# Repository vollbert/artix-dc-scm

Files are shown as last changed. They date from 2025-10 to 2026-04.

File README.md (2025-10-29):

# Artix DC-SCM

Copyright (c) 2020-2025 [Antmicro](https://www.antmicro.com)





## Overview

This repository contains design files for an open-source Baseboard Management Controller (BMC) module based on the Xilinx Artix-7 FPGA family, designed in accordance with the Data Center Secure Control Module (DC-SCM) specification of Open Compute Project (OCP).

The design files were prepared in KiCad 9.x.

## Repository structure

The main repository directory contains KiCad PCB project files, a LICENSE and README.
The remaining files are stored in the following directories:

* `img` - contains graphics for this README

## Key Features

* Artix-7 FPGA - XC7A100T-FGG484
* DC-SCI standard 168-pin 4C+ edge connector
* On-board DDR3 DRAM (AS4C256M16D3) and eMMC (MTFC16GAPALNA-AIT)
* 4x SPI FLASH memory
* Gigabit Ethernet over KSZ9031RNXCA PHY
* JTAG connector
* Host and client USB (over USB3300-EZK-TR PHY)
* M.2 NVMe interface
* 13x I2C buses, 4x I3C buses
* 2x UART 
* SPI connector
* RoT module connector
* TPM SPI connector

## Block diagram



License
=======

This project is published under the [Apache-2.0](LICENSE) license.

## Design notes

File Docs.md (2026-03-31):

## To Do

- Route the DDR3 memory
- Do the Delay Matching for DDR3 memory
- check the validation of the pinout
- get the Correct values for the 100 Ohm differential pairs
- place the capacitors and resistors to the correct locations for the ddr3 chip
    - 4 capacitors were missing in original

- for next iteration
    - what to do with rot module interface
        - only keep one flash

SYS_PWROK_R - HPM_STBY_RST_N_R
SGPIO0_D0 U2 - SYS_PWRBTN_N_R V5
SGPIO0_DI W4 - SYS_PWROK_R p16
CHASI#_R Y3 - DBP_PREQ_N_R V2
SGPIO0_CLK W5 - DBP_PRDY_N_R W2
I2C[10]_SDA W6 - RST_PLTRST_BUF_N_R W1
SGPIO1_D0 Y6 - Spare1_R AA1
Spare0r y6 - spare1_r
SGPIO0_LD V7 - rot_cpu_rst_N_r
RSVD2 y7 - Chasi#_r
spare0_r y2 - i2c[11]_scl
irq_N_r ab1 - sgpio1_di
espi_io0 K17 - i2c[8]_sda
i2c[7]_sda E13 - espi_io1
i2c[7]_scl E13 - espi_io3 L16
i2c[6]_sda G13 - espi_reset_n
spi0_cs_n_r - espi_alert_n h18
spi0_clk_r - espi_cs0_n K18
uart0_scm_rx - espi_clk L18
espi_cs1_n - i2c[6]_clk

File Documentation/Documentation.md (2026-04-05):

## To Do

# DDR3
- [ ] Find Assembly house in munich
- [x] Route the DDR3 memory
- [ ] impedance matching
	- 50 ohm single ended
		layer 3 and 5 trace thickness 0.175mm from multicb datasheet 
	- 100 Ohm differential 
		- 0.11 / 0.16mm (used calculator tool) 
- [ ] include all tha package delays
- [ ] replace obsolete .. with alternative
- MT41K256M16TW-093:P:  DDR3L 256x16 with speed grade 2133
	- make s skew limits much more relaxed

- [ ] Do the Delay Matching for DDR3 memory
![[Pasted image 20260326165011.png]]
![[Pasted image 20260403101223.png]]
Currently current configuration max dq skew 67ps for pair 1
- [x] check the validation of the pinout
	![[Pasted image 20260325133729.png]]
	![[Pasted image 20260325133813.png]]
- [ ] get the Correct values for the 100 Ohm differential pairs
- [ ] place the capacitors and resistors to the correct locations for the ddr3 chip
    - 4 capacitors were missing in original
	- Capacitors way to far from the power pins
	- Why are a handful of caps footprint 0201 x5R +-20 percent (makes no sense) either all or none for the same class. makes manufacturing harder
- [x] Changed Clock Termination According to UG589 from 
		![[Pasted image 20260325125533.png]]
		to
		![[Pasted image 20260325125712.png]]
		![[Pasted image 20260325125657.png]]
- [ ] 

## Ethernet
- [ ] "RGMII v2.0 is supported at 1.8V in HP I/O or up to 2.5V in HR I/O"  
	- i think i stay with the 3.3V 
	![[Pasted image 20260325150038.png]]	
- [.] Add series termination resistors on transmitter sides for rgmii
- [ ] impedance matching 50 rgmii and 100 ohm differential ethernet 

## USB

## eMMC
- [ ] chip obsolete find alternative to MTFC16GAPALNA-AIT 
	- all micron parts with unclear lifecycle information
	- SFEM016GB2ED1TO-I-5E-111-STD : 16Gb better write speed and active lifecycle

# Things to consider for Second design
- Better stackup with thinner traces (other manufacturer)
- replace 0402 with 0201 resistors and caps to improve routing
- clock with higher than 400mhz ddr but check impedance (i think you need 40 ohm for this)

## Pcie
- Differential Pair 85 Ohm +- 10%

## Qspi
Routing is not optimal.. place flash further to the fpga and maybe only use one flash without ROT Module connector.

## New Caps
- for 4.7uF use 0603: smaller packages have bigger voltage drop at 3.3V
	- Voltage rating doesn't affect the voltage drop therefore use 6.3V rated 
	- [**C0603C475K9PAC**](https://yageogroup.com/products?search=C0603C475K9PAC)  	
	- 

# JTAG Chip not available
- use this instead -> JTAG-HS3 Programming Cable
- https://www.digikey.de/en/products/detail/digilent-inc/410-299/5015666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

# Consolidate BOM
- Reassign all parts in Kicad directly

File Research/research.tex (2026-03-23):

\documentclass[11pt]{article}
\usepackage[utf8]{inputenc}
\usepackage[margin=1in]{geometry}
\usepackage{booktabs}
\usepackage{hyperref}
\usepackage{graphicx}

% \title{Design Review: Artix DC-SCM PCB Fabrication}
% \author{Fabian}
% \date{\today}

\begin{document}

% \maketitle

\section{BOM Obsolescence}
The following components are obsolete:
\begin{itemize}
    \item \textbf{DDR3 SDRAM:} Alliance AS4C256M16D3-12BIN. 
    \item \textbf{eMMC Flash:} Micron MTFC16GAPALNA-AIT-ND.
\end{itemize}

\section{PCB Fabrication \& DFM Blockers}
\begin{itemize}
    \item \textbf{Non-Standard Via Stackup:} Current design uses L1--L6 blind vias. This is asymmetrical for an 8-layer board and requires expensive sequential lamination. Or it can't be manufactured by most manufacturers.

    \item \textbf{Unoptimized DRC Rules:} The Default Design constraints are messy(figure \ref{fig:design-constrains}). For example 0mm clearance between Tracks. After i changed those values to minimum values of different manufacturers there are some DRC Errors. (Example \ref{fig:weirdtrace}) 

    \item Different Stackup in Fabrication Files, Website and in the Kicad setup: I checked the impedances for the different stackups and only the impedance in the fabrication file leads to the correct impedance. 

    \item Unnecessary restrictive constrains makes the design not well suited for Manufacturability which is why most manufacturers are not able to manufacture the board. 

\end{itemize}

\begin{figure}[h]
  \centering
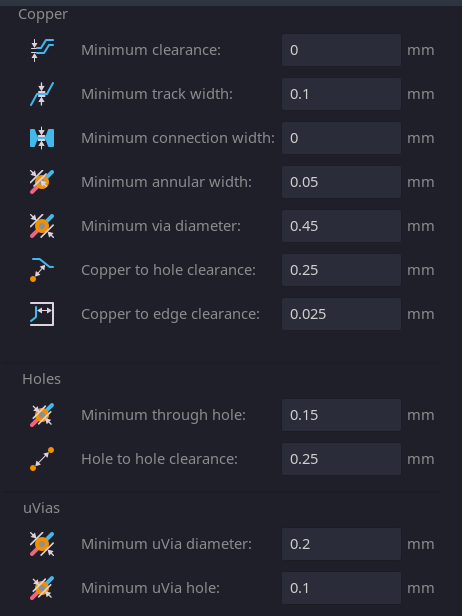
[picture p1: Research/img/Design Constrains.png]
  
  \caption{}
  \label{fig:design-constrains}
\end{figure}

\begin{figure}[h]
  \centering
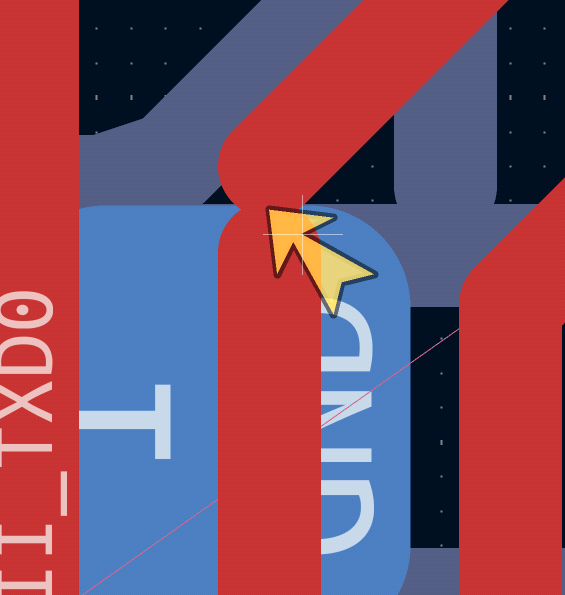
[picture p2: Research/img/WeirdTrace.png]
  
  \caption{}
  \label{fig:weirdtrace}
\end{figure}

\section{Impedance Issues}

Impedances are matched using Online Calculators. Kicads Internal tool leads to different Impedance values. Online Calculators are not sufficient for small traces and spacing!!

\section{Before Ordering}
\begin{itemize}
  \item Check Minor DRC Errors
  \item Try to get rid of 1-6 vias and replace them with through hole vias.
  \item Choose one manufacturer and change the traces to have the right impedance for their stackup
  \item Check Impedances \textbf{Impedance Control}: Factory changes the traces based on their parameters.
\end{itemize}

\section{PCB Manufacturers}
Since there are so hard constrains i had to search for many different manufacturers and see if they are able to manufacture the board. So far i checked the following ones. For the prices i calculated 5 boards since it is the minimum for many assembly houses.
\begin{itemize}
  \item \textbf{PCBWay}: I requested a quote from them to have a baseline for the price. They are able to manufacture any layer HDI boards. For 5 boards: \$758.53(Without tax) + 
\$ 1656.37 for assembly including the parts
  \item \textbf{Eurocircuit}: Can't manufacture 1-6 vias for 8 layer board. Also no via stacking. Without those vias: € 3538.92 (Only so expensive because of hard constrains)
  \item \textbf{Wuerth Electronics}1-6 via not possible for their normal stackups. € 1.320,75	with less strict constrains
  \item \textbf{Multi-CB} Should be capable of creating the PCB but has no assembly service. Since This is a really custom stackup i had to request manually and still have no reply. (706.52 € for only one pcb)
  \item \textbf{Leiton}Should be capable of creating the PCB and assemble but since this is a really special request this is only done manually and i have no reply yet.
\end{itemize}

\section{Modification Estimate: 32x IO Integration}
Should be doable. This (figure \ref{fig:areaasic}) has some space that should be enough to route the traces to the asic depending on the footprint size. If there is not enough space I have to move some footprints and do most of the routing again. Since the FPGA has a relatively large pitch maybe it would be better to do the routing again and optimize for Manufacturability.

Check IO voltages

\begin{figure}[h]
  \centering
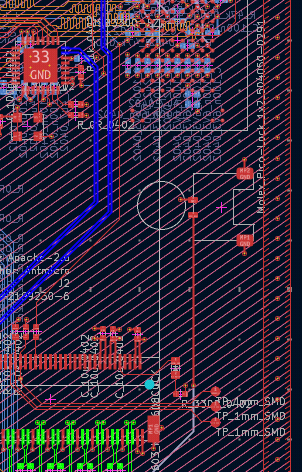
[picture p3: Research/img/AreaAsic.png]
  
  \caption{}
  \label{fig:areaasic}
\end{figure}

\section{Impedance Control Requirements}
\begin{center}
\begin{tabular}{l l l}
\toprule
\textbf{Interface} & \textbf{Signal Type} & \textbf{Target Impedance} \\
\midrule
PCIe Gen 2 & Differential Pairs & 85$\Omega \pm 10\%$ \\
Ethernet (Media) & Differential Pairs & 100$\Omega \pm 10\%$ \\
RGMII (MAC side) & Single-Ended & 50$\Omega \pm 10\%$ \\
USB & Differential & 90$\Omega \pm 15\%$ \\
\bottomrule
\end{tabular}
\end{center}

\section{DDR3}

Generally, single impedances (CA, Control \& DQ’s) are 50Ω (+/- 10\%) 
and differential impedances (Clocks, DQS’s) are nominally 100Ω (+/- 10\%) and are typically routed on inner layers if 
possible.
\\

The following are general guidelines for PDN development in DDR3 board designs. 
\begin{itemize}
\item1. Solid Power and Ground planes should be used in DDR3 routing areas. 
\item2. Place a 0.1uF cap and 0.01uF as close as possible for every VDDQ pin. 
\item3. VTT decoupling should be as close to the components and pull-up resistors as possible. 
\item4. Place a 0.1uF decoupling cap between VTT and VDD. 
\item5. Low ESL decoupling capacitors should be used, and routing should be carefully evaluated to minimize 
inductance. 
\item 6. Power connections from supply planes to vias for device pins or decoupling capacitors should be as short ($<$8 
mils) and as wide as possible (trace widths should be the same or larger than the via size) to minimize trace 
impedance. 
\end{itemize}

\section{changed}

- changed ddr3\_clk\_p with ddr3\_a9 (easier routing)
- changed ddr3\_clk\_n with ddr3\_a5

\end{document}

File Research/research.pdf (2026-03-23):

## 1 BOM Obsolescence

The following components are obsolete:

- DDR3 SDRAM: Alliance AS4C256M16D3-12BIN.
- eMMC Flash: Micron MTFC16GAPALNA-AIT-ND.

## 2 PCB Fabrication & DFM Blockers

- Non-Standard Via Stackup: Current design uses L1–L6 blind vias. This is asymmetrical for an 8-layer board and requires expensive sequential lamination. Or it can’t be manufactured by most manufacturers.
- Unoptimized DRC Rules: The Default Design constraints are messy(figure 1). For example 0mm clearance between Tracks. After i changed those values to minimum values of different manufacturers there are some DRC Errors. (Example 2)
- Different Stackup in Fabrication Files, Website and in the Kicad setup: I checked the impedances for the different stackups and only the impedance in the fabrication file leads to the correct impedance.
- Unnecessary restrictive constrains makes the design not well suited for Manufacturability which is why most manufacturers are not able to manufacture the board.

## 3 Impedance Issues

Impedances are matched using Online Calculators. Kicads Internal tool leads to different Impedance values. Online Calculators are not sufficient for small traces and spacing!!

## 4 Before Ordering

- Check Minor DRC Errors
- Try to get rid of 1-6 vias and replace them with through hole vias.
- Choose one manufacturer and change the traces to have the right impedance for their stackup
- Check Impedances Impedance Control: Factory changes the traces based on their parameters.

## 5 PCB Manufacturers

Since there are so hard constrains i had to search for many different manufacturers and see if they are able to manufacture the board. So far i checked the following ones. For the prices i calculated 5 boards since it is the minimum for many assembly houses.

- PCBWay: I requested a quote from them to have a baseline for the price. They are able to manufacture any layer HDI boards. For 5 boards: $758.53(Without tax) + $ 1656.37 for assembly including the parts

- Eurocircuit: Can’t manufacture 1-6 vias for 8 layer board. Also no via stacking. Without those vias: € 3538.92 (Only so expensive because of hard constrains)
- Wuerth Electronics1-6 via not possible for their normal stackups. € 1.320,75 with less strict constrains
- Multi-CB Should be capable of creating the PCB but has no assembly service. Since This is a really custom stackup i had to request manually and still have no reply. (706.52 € for only one pcb)
- LeitonShould be capable of creating the PCB and assemble but since this is a really special request this is only done manually and i have no reply yet.

## 6 Modification Estimate: 32x IO Integration

Should be doable. This (figure 3) has some space that should be enough to route the traces to the asic depending on the footprint size. If there is not enough space I have to move some footprints and do most of the routing again. Since the FPGA has a relatively large pitch maybe it would be better to do the routing again and optimize for Manufacturability.
Check IO voltages

## 7 Impedance Control Requirements

Interface | Signal Type | Target Impedance
PCIe Gen 2 | Differential Pairs | 85Ω ± 10%
Ethernet (Media) | Differential Pairs | 100Ω ± 10%
RGMII (MAC side) Single-Ended | 50Ω ± 10%
USB | Differential | 90Ω ± 15%

## 8 DDR3

Generally, single impedances (CA, Control & DQ’s) are 50Ω (+/- 10%) and differential impedances (Clocks, DQS’s) are nominally 100Ω (+/- 10%) and are typically routed on inner layers if possible.

The following are general guidelines for PDN development in DDR3 board designs.

- 1. Solid Power and Ground planes should be used in DDR3 routing areas.
- 2. Place a 0.1uF cap and 0.01uF as close as possible for every VDDQ pin.
- 3. VTT decoupling should be as close to the components and pull-up resistors as possible.
- 4. Place a 0.1uF decoupling cap between VTT and VDD.
- 5. Low ESL decoupling capacitors should be used, and routing should be carefully evaluated to minimize inductance.
- 6. Power connections from supply planes to vias for device pins or decoupling capacitors should be as short (<8 mils) and as wide as possible (trace widths should be the same or larger than the via size) to minimize trace impedance.

## 9 changed

- changed ddr3 clk p with ddr3 a9 (easier routing) - changed ddr3 clk n with ddr3 a5


Figure 1:

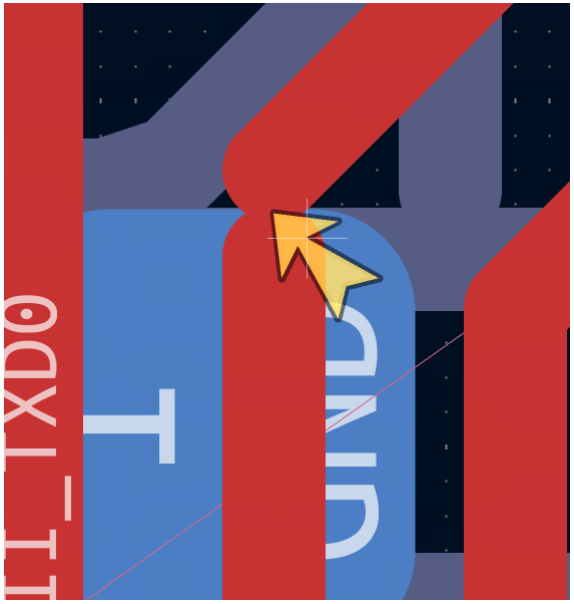
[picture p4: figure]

Figure 2:

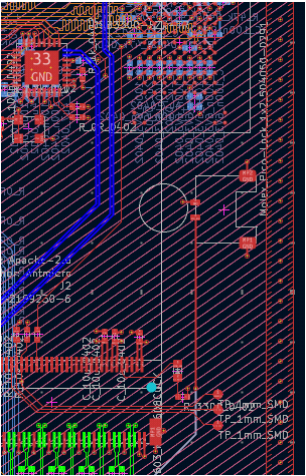
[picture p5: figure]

Figure 3:

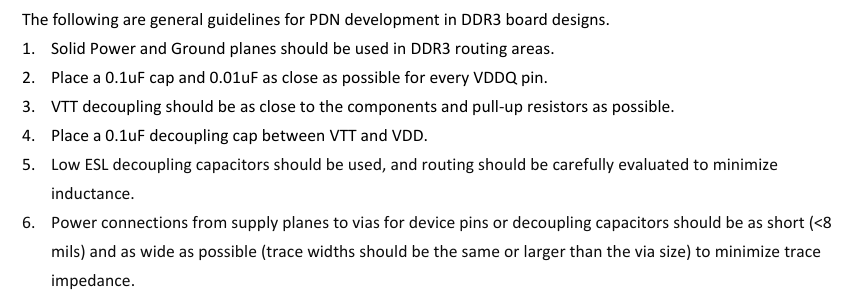
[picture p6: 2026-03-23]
Research/img/DDR3Rules.png

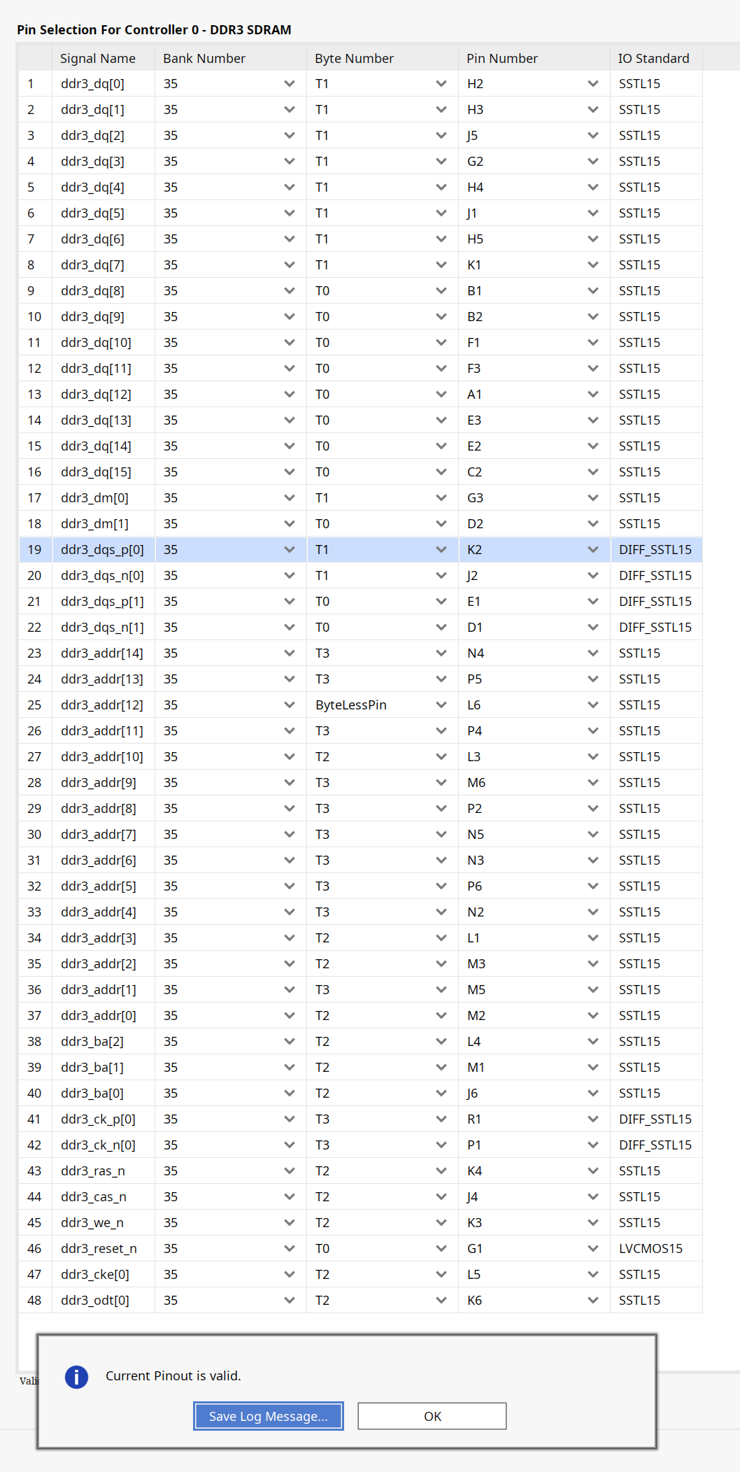
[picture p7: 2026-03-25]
Documentation/Pasted image 20260325133729.png

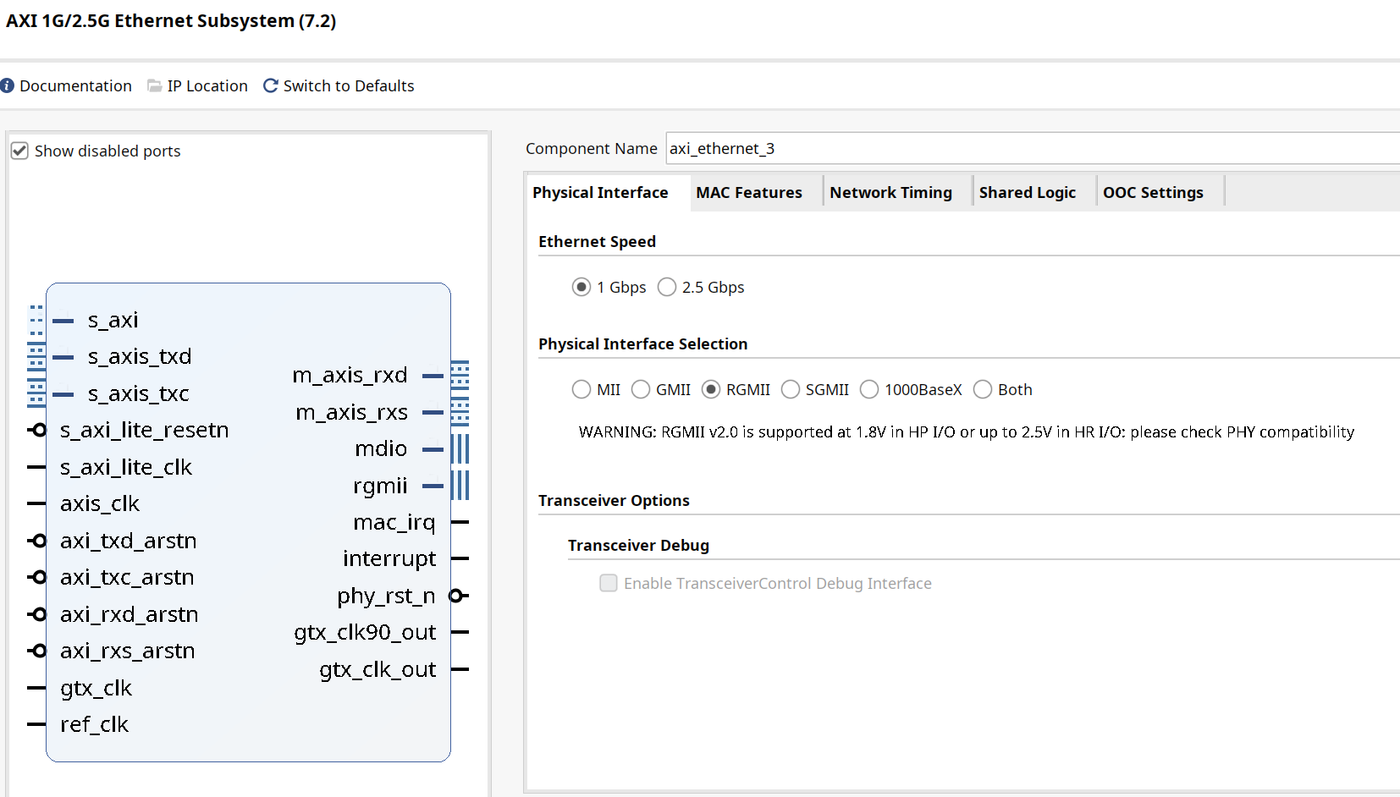
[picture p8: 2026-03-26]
Documentation/Pasted image 20260325150038.png

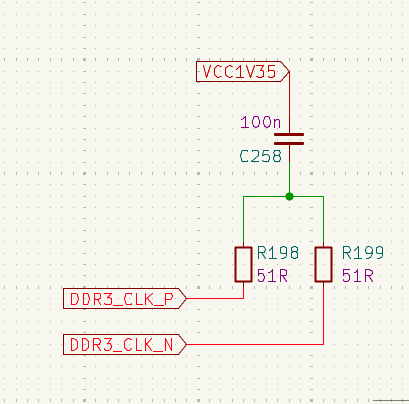
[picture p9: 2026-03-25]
Documentation/Pasted image 20260325125712.png

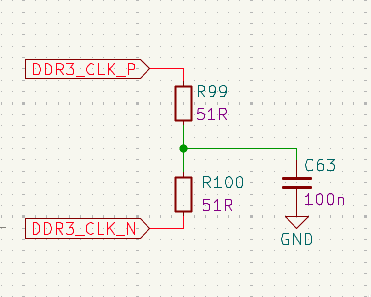
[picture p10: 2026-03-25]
Documentation/Pasted image 20260325125533.png

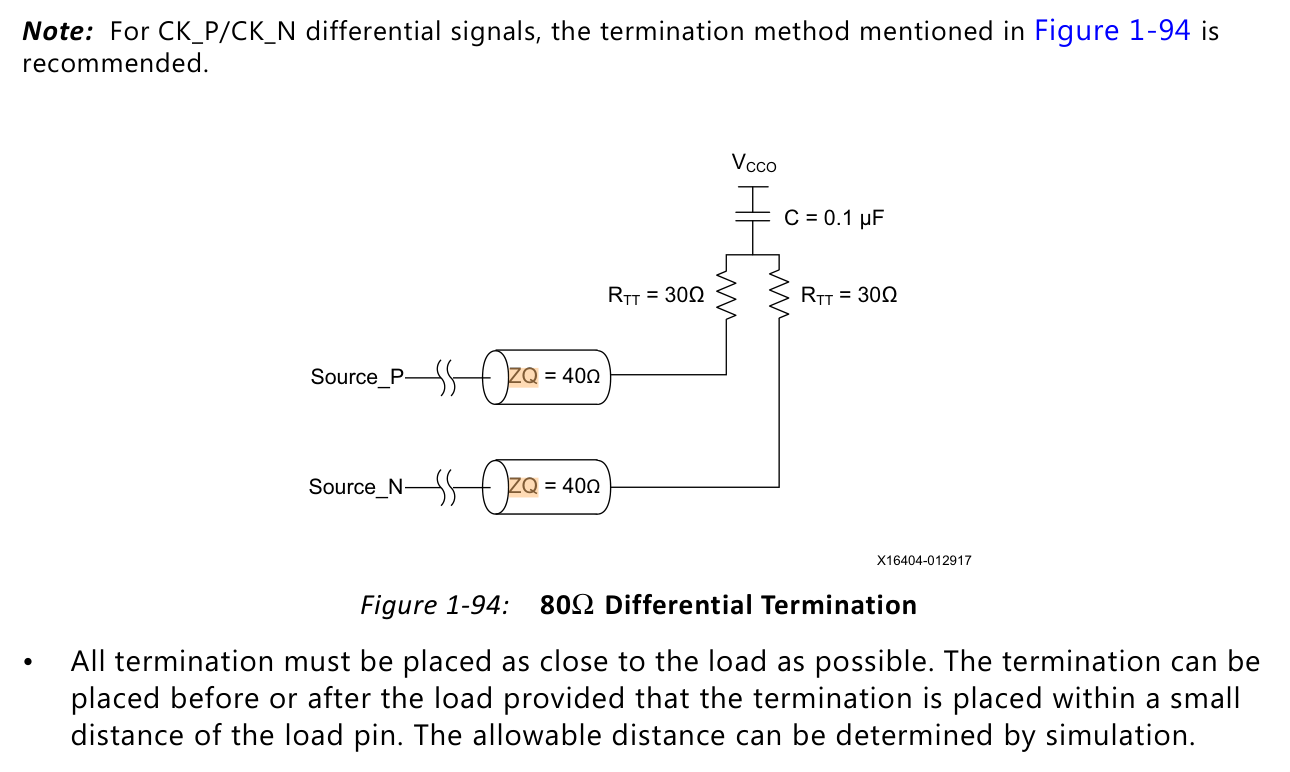
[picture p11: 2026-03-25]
Documentation/Pasted image 20260325125657.png

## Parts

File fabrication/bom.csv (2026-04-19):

Id | Designator | Footprint | Quantity | Designation | Supplier and ref
1 | C1 | C_0402_1005Metric | 1 | C_1n_0402
2 | C2, C75, C76, C77, C78 | C_0603_1608Metric | 5 | C_10u_0603
3 | C3, C79, C80, C81, C82 | C_0402_1005Metric | 5 | C_120p_0402
4 | C4, C5, C6, C7, C10, C11, C12, C13, C18, C19, C20, C21, C22, C24, C25, C26, C107, C135, C139, C149, C169, C170, C172, C173, C174, C203, C225, C226, C227, C228, C233, C248, C249, C251, C252, C253, C254, C261 | C_0402_1005Metric | 38 | C_100n_0402
5 | C8, C9, C35, C36, C37, C38, C49, C50, C51, C52, C53, C54, C55, C56, C58, C59, C60, C61, C109, C110, C111, C112, C113, C114, C115, C116, C117, C118, C119, C120, C121, C122, C123, C124, C125, C126, C127, C128, C129, C130, C131, C132, C138, C140, C141, C142, C143, C144, C146, C148, C152, C153, C157, C159, C161, C163, C165, C167, C171, C175, C197, C201, C202, C204, C205, C221, C234, C235, C236, C237, C238, C239, C240, C242, C243, C244, C255, C256, C257 | C_0402_1005Metric | 79 | C_470n_0402
6 | C14, C15, C16 | C_0603_1608Metric | 3 | C_10u_25V_0603
7 | C17, C27, C28, C29, C30, C39, C42, C44, C46, C57, C62, C63, C71, C134, C136, C179, C180, C181, C182, C186, C187, C189, C192, C193, C194, C195, C223, C224, C229, C230, C231, C232, C241 | C_0402_1005Metric | 33 | C_100n_6V3_0402
8 | C23, C48, C154, C162, C177, C188, C196, C198, C199, C200, C206, C222, C245, C246, C247, C258 | C_0402_1005Metric | 16 | C_4u7_0402
9 | C31, C32, C33, C34, C40, C41, C43, C47, C83, C84, C85, C86, C87, C88, C89, C90, C101, C103, C155, C250 | C_0402_1005Metric | 20 | C_10u_0402
10 | C45, C97, C98, C99, C100, C102, C104, C105, C106, C108, C137, C156, C158, C160, C164, C190, C191, C259, C260 | C_0603_1608Metric | 19 | C_4u7_0603
11 | C64, C69, C207, C208, C209, C210, C211, C212, C213, C214, C215, C216, C217, C218, C219 | C_0402_1005Metric | 15 | C_10n_0402
12 | C65, C66, C67 | C_0603_1608Metric | 3 | C_2u2_0603_25V
13 | C68 | C_0402_1005Metric | 1 | C_4n7_0402
14 | C70 | C_0402_1005Metric | 1 | C_47p_0402
15 | C72, C73, C74 | C_0603_1608Metric | 3 | C_47u_0603
16 | C91, C92, C93, C94, C95, C96, C133, C147, C178 | C_1210_3225Metric | 9 | C_47u_1210
17 | C145, C151 | C_1210_3225Metric | 2 | C_100u_1210
18 | C150 | C_Pol_EIA-D | 1 | C_Pol_330u_6.3V_KEMET-T520-D
19 | C166, C168 | C_0402_1005Metric | 2 | C_18p_0402
20 | C176, C220 | C_0402_1005Metric | 2 | C_22p_0402
21 | C183, C184, C185 | C_0402_1005Metric | 3 | C_2u2_0402
22 | D1 | LED_0603_1608Metric_G | 1 | LED_G_0603_KP-1608CGCK
23 | D2 | USON-14_3.5x1.35_P0.5mm | 1 | SP3011-06UTG
24 | D3 | PowerDI5 | 1 | PDS760
25 | D4, D5, D6, D7, D8, D9, D10, D11, D12, D13, D14 | LED_0603_1608Metric_G | 11 | LED_G_0603_LG_L29K-G2J1-24-Z
26 | D15 | SOT-723 | 1 | TPD2E009_SOT-9X3
27 | F1 | F_1206_3216Metric | 1 | F_3A_1206
28 | FB1, FB2 | FB_0402_1005Metric | 2 | FB_600Z_0.3A_Murata-BLM15AG_0402
29 | FB4, FB5, FB6 | FB_0603_1608Metric | 3 | FB_120Z_2A_Murata-BLM18PG_0603
30 | H1 | Spacer_Drill3.7mm_H2.5mm_9774025151R | 1 | Spacer_Drill3.7mm_H2.5mm_9774025151R
31 | H2 | Spacer_Drill3.7mm_H4mm_9774040151R | 1 | Spacer_Drill3.7mm_H4mm_9774040151R
32 | J1 | RJ45_BEL_L834-1G1T-S7 | 1 | L834-1G1T-S7
33 | J2 | Bus_M.2_Socket_Key_M_TE_1-2199230-6 | 1 | Bus_M.2_1-2199230-6
34 | J3 | USB-Micro-B_Receptacle_Amphenol_10118192 | 1 | USB-Micro-B_Amphenol_10118192-0001LF
35 | J4 | PinSocket_2x6_P2.54mm_Drill1.02mm_PMOD | 1 | PinSocket_2x6_P2.54mm_Drill1.02mm_PMOD
36 | J5, J10 | Conn_Molex_Pico-Lock_1x2_504050-0291 | 2 | Molex_Pico-Lock_1x2_504050-0291
37 | J6 | PinHeader_2x7_P2mm_Drill0.9mm_878311420 | 1 | PinHeader_2x7_P2mm_Drill0.9mm_878311420
38 | J7 | PinHeader_1x6_P2.54mm_Drill1.1mm | 1 | PinHeader_1x6_P2.54mm_Drill1.1mm
39 | J8 | Conn_Plug_Molex_SlimStack_2x25_529910508 | 1 | Plug_Molex_SlimStack_2x25_529910508
40 | J13 | PinHeader_1x3_P2.54mm_Drill1.1mm | 1 | PinHeader_1x3_P2.54mm_Drill1.1mm
41 | L1 | L_WE-PDF-1064 | 1 | L_7u2_7.9A_WE-PDF-1064
42 | L2, L3, L4, L5, L6 | L_Vishay-IHLP-1212AE | 5 | L_470n_6.7A_Vishay-IHLP-1212AE-11
43 | PROG_B1 | SW_KMR211NGLFS_SMD | 1 | SW_KMR211NGLFS_SMD
44 | Q1, Q2, Q3, Q4, Q5, Q6 | SC70-3 | 6 | BSS138PW
45 | Q12, Q13, Q14, Q15, Q16 | SOT-23-3 | 5 | 2N7002_SOT-23-3
46 | R1, R2, R6, R8, R25, R26, R27, R28, R94, R95, R96, R97, R98, R128, R129, R130, R131, R132, R190 | R_0402_1005Metric | 19 | R_1k_0402
47 | R3, R159 | R_0402_1005Metric | 2 | R_12k1_0402
48 | R5, R7 | R_0402_1005Metric | 2 | R_12k_0402
49 | R9, R160, R191, R192, R193, R195, R196 | R_0402_1005Metric | 7 | R_22R_0402
50 | R10, R11, R14, R15, R16, R81, R84, R101, R102, R103, R104, R105, R106, R107, R108, R109, R110, R111, R112, R114, R115, R116, R136, R137, R138, R144, R145, R146, R147, R154, R161, R185 | R_0402_1005Metric | 32 | R_0R_0402
51 | R12, R53, R62, R75 | R_0402_1005Metric | 4 | R_200k_0402
52 | R13, R21, R22, R23, R24, R85, R89, R90, R134, R135, R155 | R_0402_1005Metric | 11 | R_4k7_0402
53 | R17, R19, R20, R29, R30, R31, R32, R33, R34, R35, R36, R37, R38, R39, R40, R41, R42, R43, R44, R57, R58, R59, R61, R91, R92, R93, R113, R189 | R_0402_1005Metric | 28 | R_10k_0402
54 | R18 | R_0402_1005Metric | 1 | R_330R_0402
55 | R45, R46, R47, R48, R49, R50, R51, R52 | R_0402_1005Metric | 8 | R_357k_0402
56 | R54, R55, R56, R99, R100, R162, R163, R164, R167, R168, R169, R170, R171, R172, R173, R174, R175, R176, R177, R178, R179, R180, R181, R182, R183, R184 | R_0402_1005Metric | 26 | R_51R_0402
57 | R60 | R_0402_1005Metric | 1 | R_240R_0402
58 | R63, R64, R65, R68, R74, R76, R78, R80, R186, R187 | R_0402_1005Metric | 10 | R_100k_0402
59 | R66 | R_0402_1005Metric | 1 | R_16k9_0402
60 | R67 | R_0402_1005Metric | 1 | R_243k_0402
61 | R69 | R_1206_3216Metric | 1 | R_0R_1206
62 | R70 | R_0402_1005Metric | 1 | R_49R9_0402
63 | R71 | R_0402_1005Metric | 1 | R_53k6_0402
64 | R72, R127, R148, R149, R150, R151, R152, R153, R156, R157, R158 | R_0402_1005Metric | 11 | R_10k2_0402
65 | R73 | R_0402_1005Metric | 1 | R_453k_0402
66 | R77 | R_0402_1005Metric | 1 | R_66k5_0402
67 | R79 | R_0402_1005Metric | 1 | R_124k_0402
68 | R86, R87, R143 | R_0402_1005Metric | 3 | R_100R_0402
69 | R88 | R_0402_1005Metric | 1 | R_200R_0402
70 | R117, R118, R119, R120, R121, R122, R123, R124, R125, R126 | R_0402_1005Metric | 10 | R_47k_0402
71 | R133 | R_0402_1005Metric | 1 | R_2k2_0402
72 | R139, R140, R141, R142, R188 | R_0603_1608Metric | 5 | R_0R_0603
73 | R165, R166 | R_0402_1005Metric | 2 | R_220R_0402
74 | R194 | R_0402_1005Metric | 1 | R_1M8_0402
75 | R198, R199, R200, R201, R202, R203, R204, R205, R206, R207, R208, R209 | R_0402_1005Metric | 12 | R_33R_0402
76 | R210 | R_0402_1005Metric | 1 | R_2k2_0402
77 | R211, R212, R213 | R_0402_1005Metric | 3 | R_10k_0402
78 | R214 | R_0402_1005Metric | 1 | R_1k_0402
79 | U1 | BGA-170-100_18x14mm_Layout17x10_P1mm | 1 | SFEM016GB1ED1TO-I-5E-311-STD
80 | U2, U3, U4, U5 | SOIC-8_5.3x5.3x2mm_P1.27mm | 4 | W25Q32JW_SOIC-8
81 | U6 | VQFN-20_1EP_4.5x2.5mm_P0.5mm | 1 | NVT2008BQ,115
82 | U7 | BGA96C80P9X16_800X1400X120 | 1 | MT41K256M16TW-093:P
83 | U8 | VSON-10-1EP_3x3mm | 1 | TPS51200DRCT
84 | U9 | VSSOP-8_3x3mm_P0.65mm | 1 | LM3881
85 | U10, U11, U12, U13, U16 | QFN-8_2x1.5mm | 5 | TPS62823DLCT
86 | U14 | BGA-484_23x23mm_Layout22x22_P1mm_FGG484 | 1 | XC7A100T-FGG484
87 | U15 | Oscillator_SMD_Abracon_AMJM_3.2x2.5mm | 1 | Oscillator_100MHz_AMJMEFB
88 | U17, U18 | QFN-32-1EP_5x5mm | 2 | USB3300-EZK-TR
89 | U20 | QFN-48-1EP_7x7x0.9mm_P0.5mm_EP3.5x3.5mm | 1 | KSZ9031RNXCA
90 | U22 | USON-6_1.45x1.0mm_P0.5mm_Texas_DRY6 | 1 | LSF0101DRYR
91 | U23, U24 | Oscillator_SMD_Abracon_ASEMB_3.2x2.5mm | 2 | Oscillator_24MHz_ASEMB
92 | U25 | WSON-10-1EP_4x4mm_P0.8mm_EP2.6x3mm | 1 | TPS54561QDPRRQ1
93 | U26 | QFN-64-1EP_9x9mm_P0.5mm_EP4.35x4.35mm | 1 | FT2232HQ
94 | U27 | SOT-23-6 | 1 | 93LCxxBxxOT
95 | Y1 | Resonator_SMD_Abracon_ABM8G_3.2x2.5mm | 1 | Resonator_12MHz_ABM8G
96 | Y2 | Resonator_SMD_Abracon_ABM8G_3.2x2.5mm | 1 | Resonator_25MHz_ABM8G

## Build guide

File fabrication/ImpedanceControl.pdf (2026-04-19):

Layer Buildup: 8L-01

1 — 50 Ω Single-Ended
Signal Layer | KiCad Name | Top Ref Bottom | Ref | Track Width
Layer 1 | F.Cu | — | In1.Cu | 0.245 mm
Layer 3 | In2.Cu | In1.Cu | In3.Cu | 0.175 mm
Layer 6 | In5.Cu | In4.Cu | In6.Cu | 0.175 mm
Layer 8 | B.Cu | In6.Cu | — | 0.245 mm

2 — 100 Ω Differential
Signal Layer | KiCad Name | Top Ref Bottom | Ref | Track Width | Diff Gap
Layer 1 | F.Cu | — | In1.Cu | 0.12 mm | 0.115 mm
Layer 3 | In2.Cu | In1.Cu | In3.Cu | 0.11 mm | 0.13 mm
Layer 6 | In5.Cu | In4.Cu | In6.Cu | 0.11 mm | 0.13 mm
Layer 8 | B.Cu | In6.Cu | — | 0.12 mm | 0.115 mm

3 — 90 Ω Differential
Signal Layer | KiCad Name | Top Ref Bottom | Ref | Track Width | Diff Gap
Layer 1 | F.Cu | — | In1.Cu | 0.18 mm | 0.12 mm
Layer 3 | In2.Cu | In1.Cu | In3.Cu | 0.11 mm | 0.11 mm
Layer 6 | In5.Cu | In4.Cu | In6.Cu | 0.11 mm | 0.11 mm
Layer 8 | B.Cu | In6.Cu | — | 0.18 mm | 0.12 mm
4 — 85 Ω Differential
Signal Layer | KiCad Name | Top Ref Bottom | Ref | Track Width | Diff Gap
Layer 1 | F.Cu | — | In1.Cu | 0.27 mm | 0.12 mm
Layer 3 | In2.Cu | In1.Cu | In3.Cu | 0.153 mm | 0.11 mm
Layer 6 | In5.Cu | In3.Cu | In6.Cu | 0.153 mm | 0.11 mm
Layer 8 | B.Cu | In6.Cu | — | 0.27 mm | 0.12 mm

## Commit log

2024-06-10 [#55652] Fix hotareas
    [artix-dc-scm.kicad_sch, ddr3.kicad_sch, edge-connector.kicad_sch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]
2024-11-05 [#68236] Update components description
    [ddr3.kicad_sch, edge-connector.kicad_sch, ethernet.kicad_sch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]
2024-11-05 [#68236] Import updated description to the PCB
2024-11-06 [#68236] Update footprints for studs, J2 and U21
    [interfaces.kicad_sch]
2024-11-06 [#68236] Update footprints for J8, F1 and SP1
    [#68236] Refresh assets
2024-11-06 [#68236] Change studs reference from SP to H
    [pcie-conn.kicad_sch, rot.kicad_sch]
2024-11-06 [#68236] Allign sch to grid
    [artix-dc-scm.kicad_sch, ddr3.kicad_sch, edge-connector.kicad_sch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]
2024-11-06 [#68236] Remove DNP property from Testpoints
    [artix-dc-scm.kicad_sch, edge-connector.kicad_sch, ethernet.kicad_sch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]
2024-11-06 [#68236] Bump rev to 1.1.3
    [artix-dc-scm.kicad_sch, ddr3.kicad_sch, edge-connector.kicad_sch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]
2024-11-06 [#68236] Fix silkscreen overlays
2024-11-07 [#68236] Update symbols and footprints, clean ERC and DRC
    [ddr3.kicad_sch, edge-connector.kicad_sch, ethernet.kicad_sch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]
2025-10-29 [#82378] Project refresh 81589
    [artix-dc-scm.kicad_sch, ddr3.kicad_sch, edge-connector.kicad_sch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]
2025-10-30 Remove wireframe assets
2026-03-23 started routing the ddr3 memory for defined stackup from Multi CB
    [artix-dc-scm.kicad_sch, ddr3.kicad_sch, edge-connector.kicad_sch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]
2026-03-24 All DDR related pins are connected. Continue with the delay matching.
    [fpga-banks-34-25-cfg.kicad_sch]
2026-03-25 fix: add history files to gitignore
    [ddr3.kicad_sch]
2026-03-26 Added Pad delays for ddr3 pins
    [ddr3.kicad_sch, flight_time.csv, fpga-banks-34-25-cfg.kicad_sch]
2026-03-26 ddr3 routing finished
    [ddr3.kicad_sch, fpga-banks-34-25-cfg.kicad_sch]
2026-03-27 pcb layout progress
    [ethernet.kicad_sch, fpga-banks-13-16.kicad_sch, interfaces.kicad_sch]
2026-03-29 a lot of routing and almost all caps of the fpga are placed down
    [artix-dc-scm-B_Cu.gbr, artix-dc-scm-B_Mask.gbr, artix-dc-scm-B_Paste.gbr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]
2026-03-30 a lot of poin swaps
    [ddr3.kicad_sch, ethernet.kicad_sch, fpga-banks-13-16.kicad_sch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]
2026-03-31 river routing
    [fpga-banks-13-16.kicad_sch, fpga-banks-34-25-cfg.kicad_sch, interfaces.kicad_sch]
2026-04-01 Almost done with the routing
    [fpga-banks-13-16.kicad_sch, fpga-banks-34-25-cfg.kicad_sch]
2026-04-02 pcb final
    [artix-dc-scm-B_Cu.gbr, artix-dc-scm-B_Mask.gbr, artix-dc-scm-B_Paste.gbr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]
2026-04-05 bom changes
    [artix-dc-scm.csv, artix-dc-scm.kicad_sch, artix-dc-scm.xlsx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]
2026-04-19 version 1.0 complete
    [ImpedanceControl.xlsx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]
